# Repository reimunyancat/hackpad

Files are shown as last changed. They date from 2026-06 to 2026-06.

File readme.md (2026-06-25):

# Hackpad — 9-Key Macropad

A custom 9-key (3x3 matrix) macropad with a rotary encoder and a 1.3" OLED, built for the Hack Club Stardance Hackpad YSWS.

- **MCU:** Seeed XIAO RP2040
- **Layout:** 3x3 switch matrix + 1 rotary encoder (EC11) + 1.3" 128x64 OLED (I2C)
- **Firmware:** KMK (CircuitPython)
- **Case:** Sandwich-style, fully 3D printed

## Gallery

### Assembled model
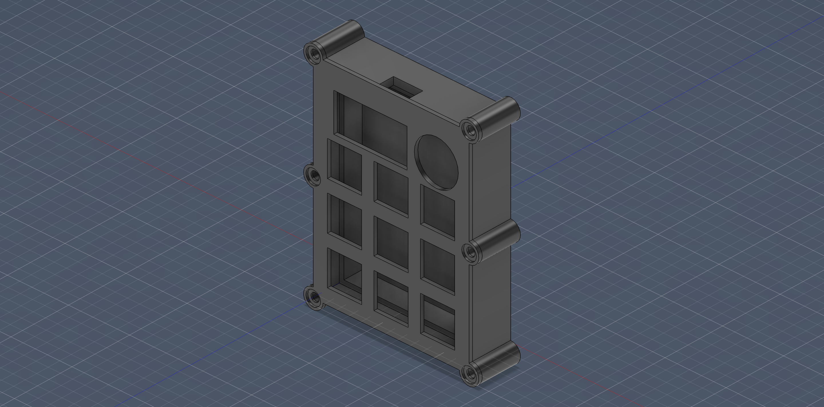
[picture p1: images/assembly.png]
Assembled


### Schematic
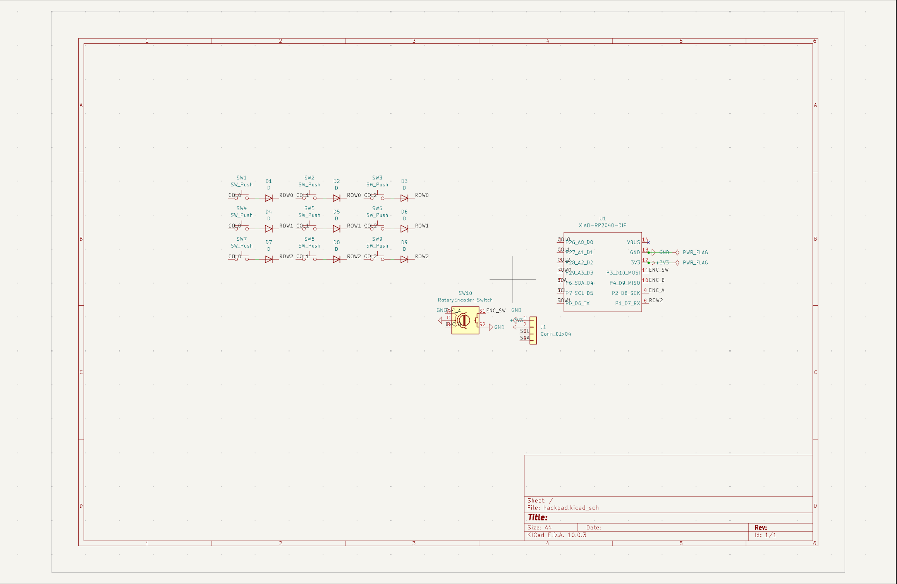
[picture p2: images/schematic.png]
Schematic


### PCB layout
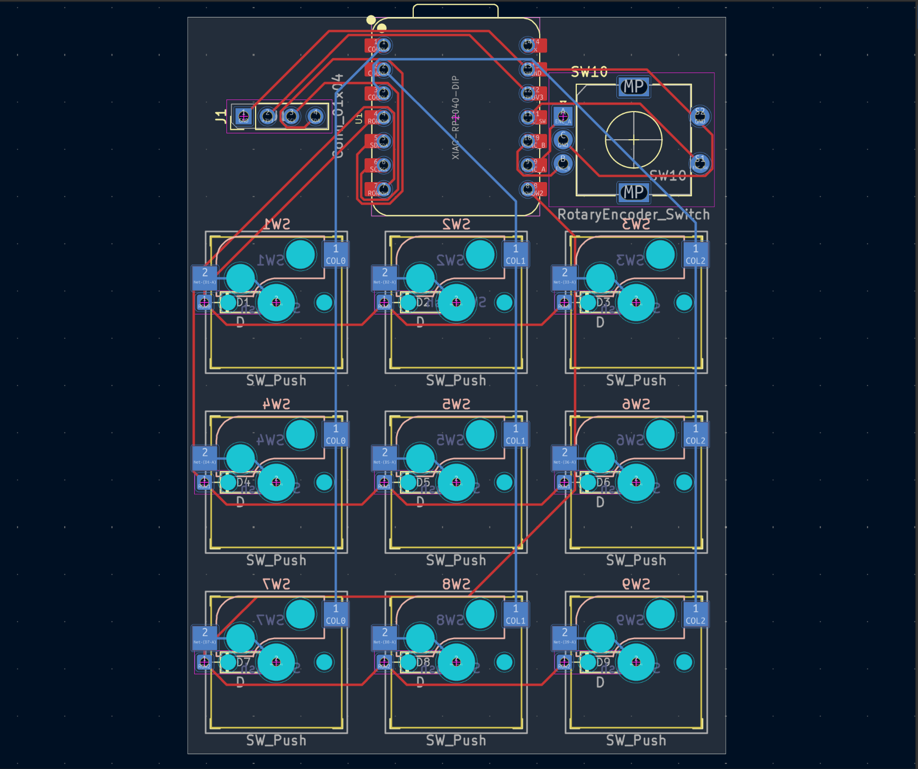
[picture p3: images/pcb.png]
PCB layout


### Case (3D)
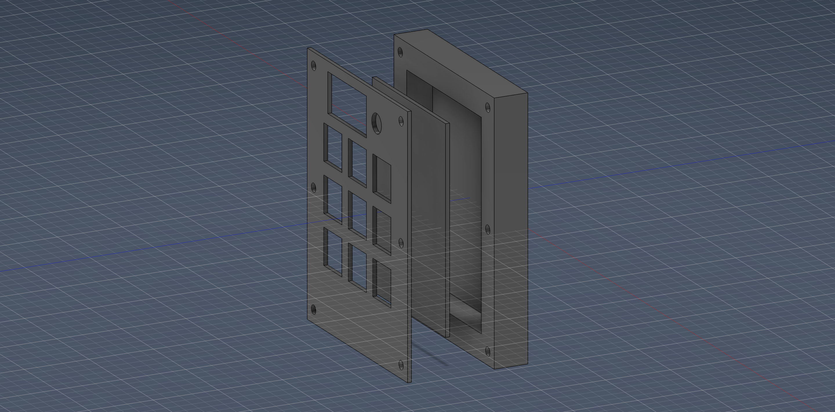
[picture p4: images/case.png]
Case


## Bill of Materials

| Component | Qty | Notes |
| --- | --- | --- |
| Seeed XIAO RP2040 | 1 | MCU (kit) |
| 1N4148 diode | 9 | matrix anti-ghosting (kit) |
| MX-style switch | 9 | (kit) |
| Kailh MX hotswap socket | 9 | self-sourced |
| EC11 rotary encoder | 1 | 20mm D-shaft (kit) |
| 1.3" 128x64 SH1106 OLED | 1 | I2C, self-sourced |
| 2.54mm 4-pin female header | 1 | OLED mount, self-sourced |
| DSA keycap | 9 | (kit) |
| M3x16 screw | 6 | (kit) |
| M3x5x4 heatset insert | 6 | (kit) |
| Custom PCB | 1 | JLCPCB, 2-layer, ~57x79mm |
| 3D printed case | 1 | top plate + bottom shell |

## Repository structure

```
.
├── README.md
├── CAD/
│   └── assembled-model.STEP
├── PCB/
│   ├── hackpad.kicad_pro
│   ├── hackpad.kicad_sch
│   └── hackpad.kicad_pcb
├── Firmware/
│   └── main.py
└── production/
    ├── gerbers.zip
    ├── Top.STEP
    ├── Bottom.STEP
    └── main.py
```

## Firmware

KMK (CircuitPython). Flash CircuitPython to the XIAO, copy the `kmk` library folder onto the CIRCUITPY drive, then drop `Firmware/main.py` on it.

Pin mapping (taken from the schematic):

- Columns: D0, D1, D2
- Rows: D3, D6, D7
- Encoder: A = D8, B = D9, SW = D10
- OLED I2C: SDA = D4, SCL = D5
- Diode orientation: COL2ROW

## Specs

- PCB: ~57x79mm, 2-layer (limit 100x100mm)
- Case: fully 3D printed (limit 200x200x100mm)
- Inputs: 9 keys + 1 encoder = 10 (limit 16)
- Tolerances: 0.2mm on mating surfaces, M3x5x4 heatset inserts (4.7mm holes), M3x16 screws (3.4mm clearance)

Note: I need a soldering iron — please include the $18 soldering iron grant.

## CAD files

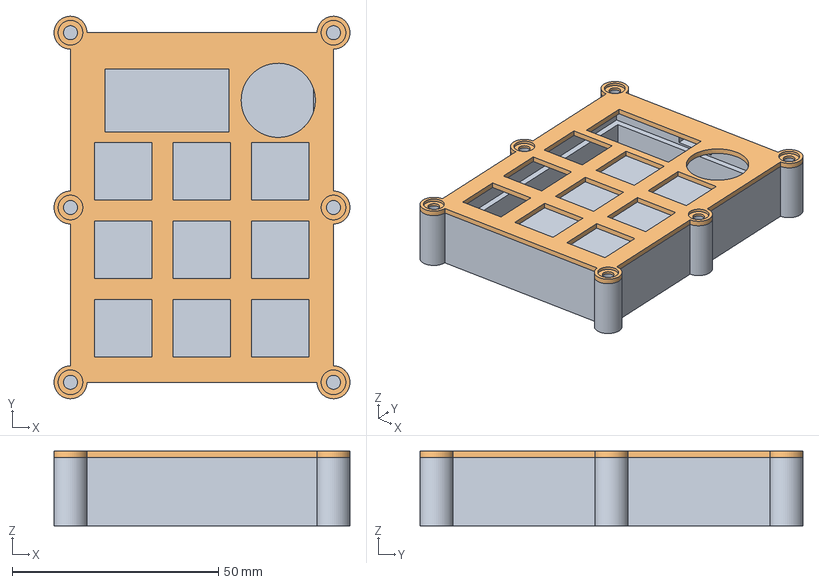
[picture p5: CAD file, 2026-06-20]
CAD/assembled-model.STEP
71.8 x 92.8 x 18.1 mm

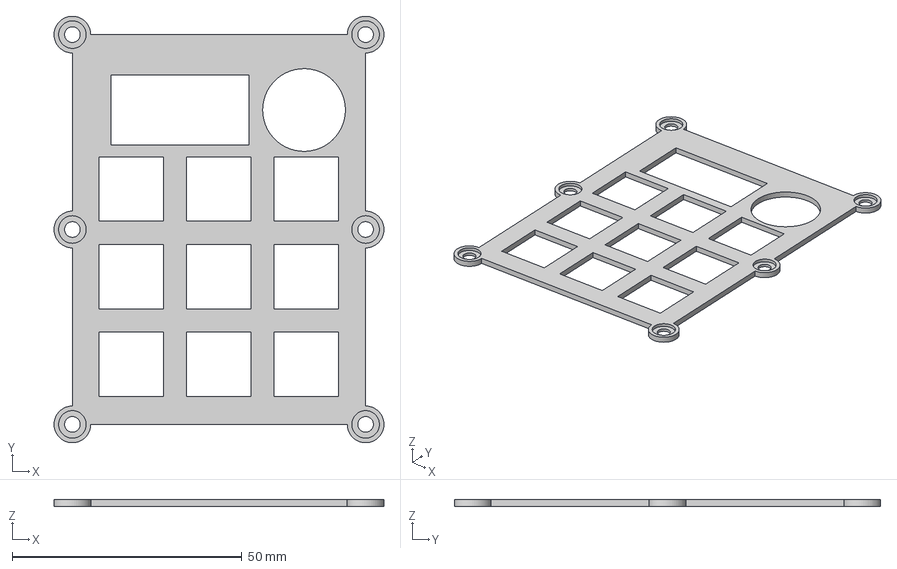
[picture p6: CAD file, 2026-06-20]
production/Top.STEP
71.8 x 92.8 x 1.50 mm

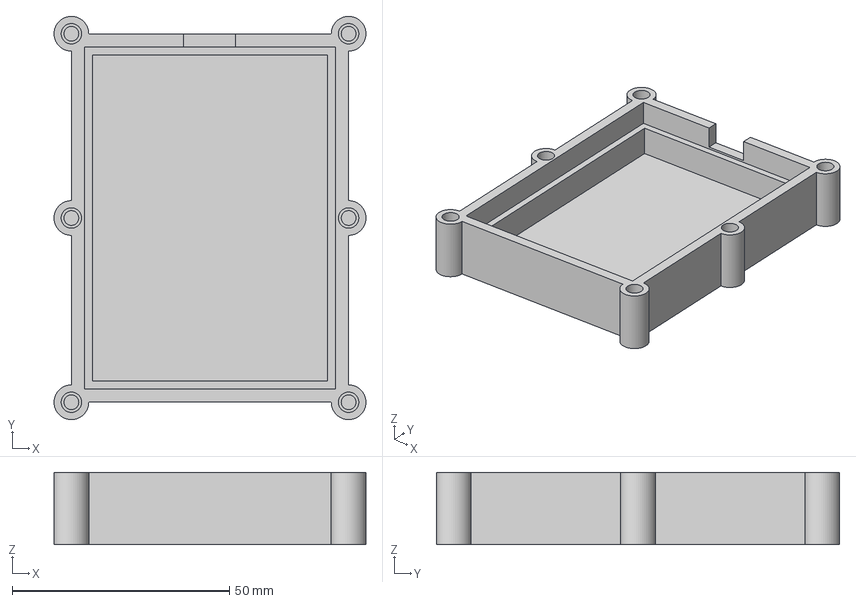
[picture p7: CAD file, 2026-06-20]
production/Bottom.STEP
71.8 x 92.8 x 16.6 mm

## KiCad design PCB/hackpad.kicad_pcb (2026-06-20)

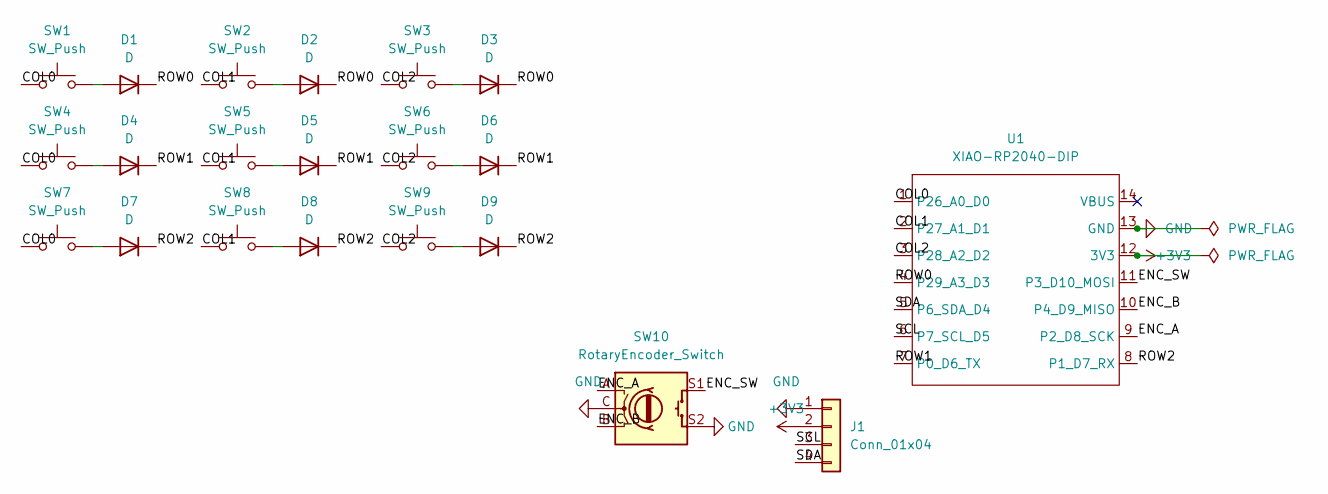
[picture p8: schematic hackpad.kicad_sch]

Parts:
D1, D2, D3, D4, D5, D6, D7, D8, D9: D; D_DO-35_SOD27_P7.62mm_Horizontal
J1: Conn_01x04; PinHeader_1x04_P2.54mm_Vertical
SW1, SW2, SW3, SW4, SW5, SW6, SW7, SW8, SW9: SW_Push; Kailh_socket_MX
SW10: RotaryEncoder_Switch; RotaryEncoder_Alps_EC11E-Switch_Vertical_H20mm
U1: XIAO-RP2040-DIP

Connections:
+3V3: J1.2, U1.12 (3V3)
/COL0: SW1.1, SW4.1, SW7.1, U1.1 (P26_A0_D0)
/COL1: SW2.1, SW5.1, SW8.1, U1.2 (P27_A1_D1)
/COL2: SW3.1, SW6.1, SW9.1, U1.3 (P28_A2_D2)
/ENC_A: SW10.A, U1.9 (P2_D8_SCK)
/ENC_B: SW10.B, U1.10 (P4_D9_MISO)
/ENC_SW: SW10.S1, U1.11 (P3_D10_MOSI)
/ROW0: D1.1 (K), D2.1 (K), D3.1 (K), U1.4 (P29_A3_D3)
/ROW1: D4.1 (K), D5.1 (K), D6.1 (K), U1.7 (P0_D6_TX)
/ROW2: D7.1 (K), D8.1 (K), D9.1 (K), U1.8 (P1_D7_RX)
/SCL: J1.3, U1.6 (P7_SCL_D5)
/SDA: J1.4, U1.5 (P6_SDA_D4)
GND: J1.1, SW10.C, SW10.S2, U1.13 (GND)
unnamed: D1.2 (A), SW1.2
unnamed: D2.2 (A), SW2.2
unnamed: D3.2 (A), SW3.2
unnamed: D4.2 (A), SW4.2
unnamed: D5.2 (A), SW5.2
unnamed: D6.2 (A), SW6.2
unnamed: D7.2 (A), SW7.2
unnamed: D8.2 (A), SW8.2
unnamed: D9.2 (A), SW9.2

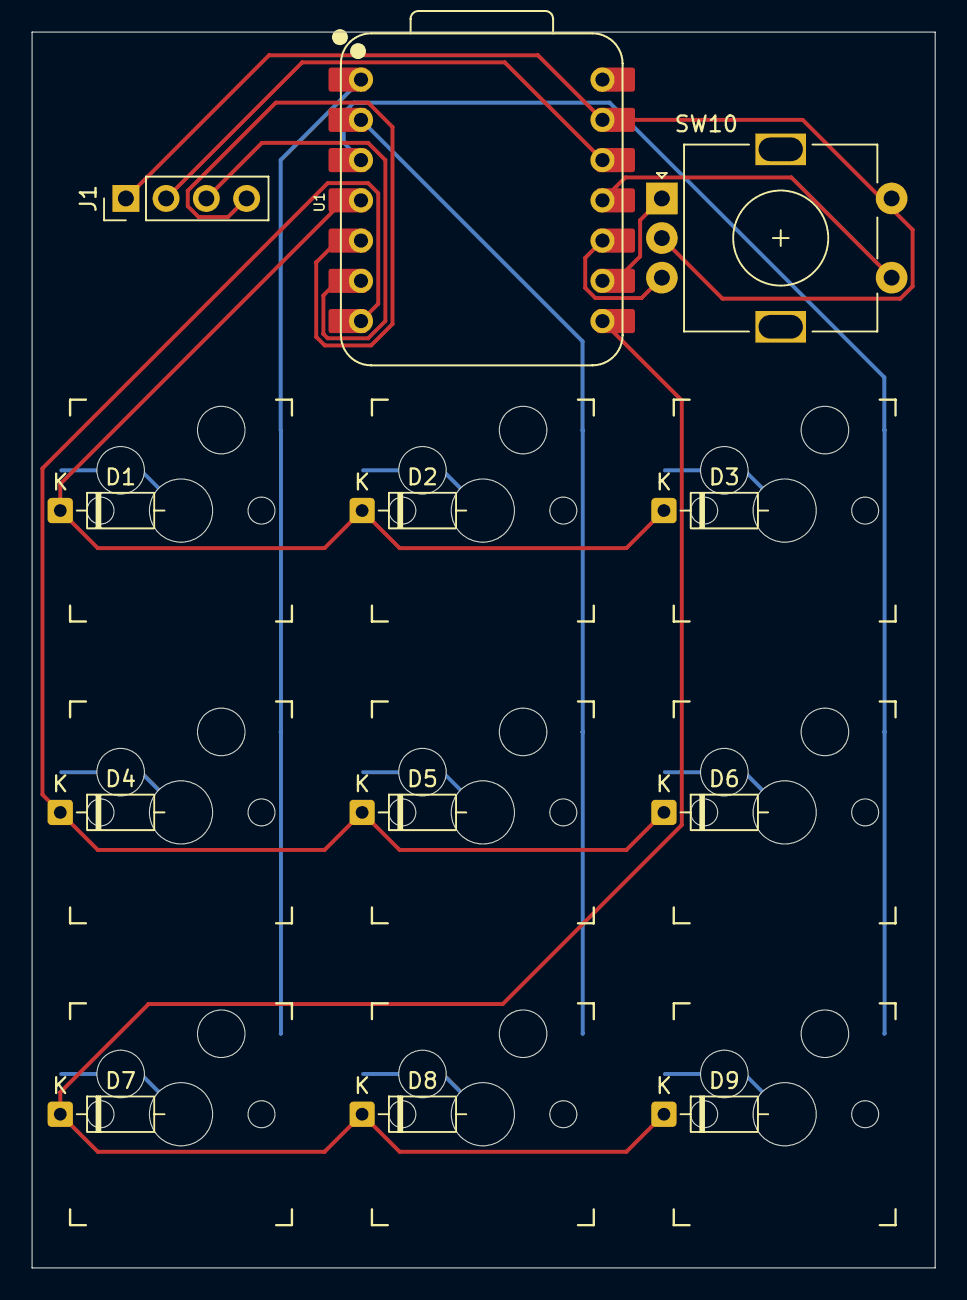
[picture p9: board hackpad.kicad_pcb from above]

Board: 2 copper layers, 57.0 x 78.0 mm, 21 parts (0 on the bottom side), 22 nets.

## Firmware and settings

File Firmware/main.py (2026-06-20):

import board
from kmk.kmk_keyboard import KMKKeyboard
from kmk.keys import KC
from kmk.scanners import DiodeOrientation
from kmk.modules.encoder import EncoderHandler

keyboard = KMKKeyboard()

keyboard.col_pins = (board.D0, board.D1, board.D2)
keyboard.row_pins = (board.D3, board.D6, board.D7)
keyboard.diode_orientation = DiodeOrientation.COL2ROW

encoder = EncoderHandler()
encoder.pins = ((board.D8, board.D9, board.D10, False),)
keyboard.modules.append(encoder)

keyboard.keymap = [
    [
        KC.LCTL(KC.C), KC.LCTL(KC.V), KC.LCTL(KC.X),
        KC.LCTL(KC.Z), KC.LCTL(KC.LSFT(KC.Z)), KC.F5,
        KC.LCTL(KC.GRAVE), KC.PSCR, KC.MUTE,
    ],
]

encoder.map = [
    ((KC.VOLD, KC.VOLU, KC.MPLY),),
]

if __name__ == "__main__":
    keyboard.go()
